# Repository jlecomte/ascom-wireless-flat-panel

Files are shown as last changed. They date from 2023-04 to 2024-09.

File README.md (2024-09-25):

# ASCOM-Compatible Wireless Flat Panel

I do not charge anything to create and maintain these open-source projects. But if you would like to say "thanks" for this project, feel free to send any amount through Paypal using the button below. I appreciate your support!

(https://www.paypal.com/donate/?hosted_button_id=49UXY8F6VVYFA)

* [Introduction](#introduction)
* [Finished Product](#finished-product)
* [User Manual](#user-manual)
* [Pre-Requisites](#pre-requisites)
* [Hardware](#hardware)
* [Bill Of Material](#bill-of-material)
* [ASCOM Driver](#ascom-driver)
  + [Downloading And Installing The Driver](#downloading-and-installing-the-driver)
  + [Compiling The Driver (For Developers Only)](#compiling-the-driver-for-developers-only)
* [Arduino Firmware](#arduino-firmware)
  + [Microcontroller Compatibility](#microcontroller-compatibility)
  + [Compiling And Uploading The Firmware](#compiling-and-uploading-the-firmware)
* [Electronic Circuit](#electronic-circuit)
  + [Schematics](#schematics)
  + [Breadboard Prototyping](#breadboard-prototyping)
  + [PCB](#pcb)
* [Mechanical Components And Assembly](#mechanical-components-and-assembly)
* [Troubleshooting](#troubleshooting)
  + [Changing the 3D model parameters to fit small telescopes](#changing-the-3d-model-parameters-to-fit-small-telescopes)
* [Frequently Asked Questions (FAQ)](#frequently-asked-questions-faq)

## Introduction

This project is the second iteration of my original DIY [ASCOM-compatible flat panel](https://github.com/jlecomte/ascom-flat-panel). It brings a major usability improvement over the first version: It is completely wireless! (whereas the first version relied on a USB type C and a 12V DC cable...) which makes it even easier to use, especially in the dark! It has several other enhancements compared to the original version, and I invite you to check out this video to find out more:

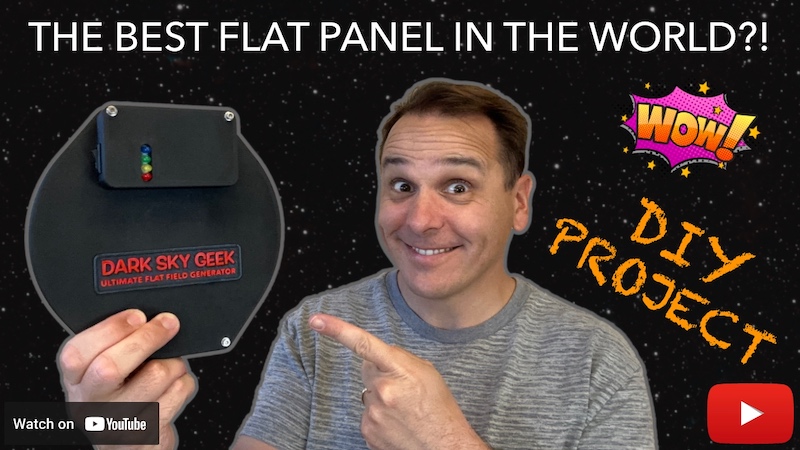
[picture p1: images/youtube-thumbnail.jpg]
YouTube video talking about this flat panel (https://www.youtube.com/watch?v=POvcBwyBBEU)


## Finished Product

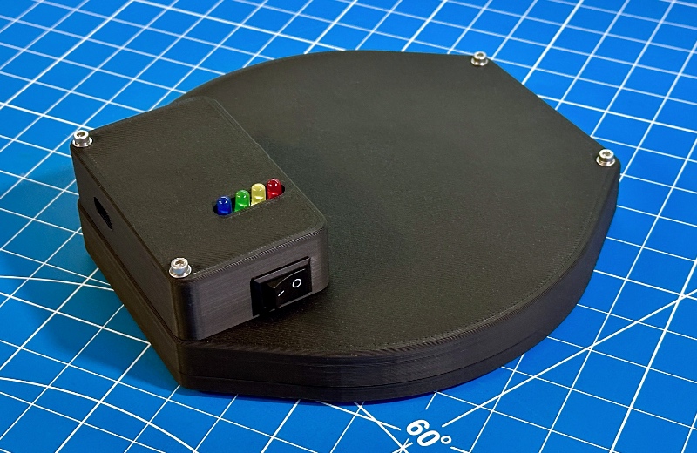
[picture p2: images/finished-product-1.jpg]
Finished product: top of the wireless flat panel


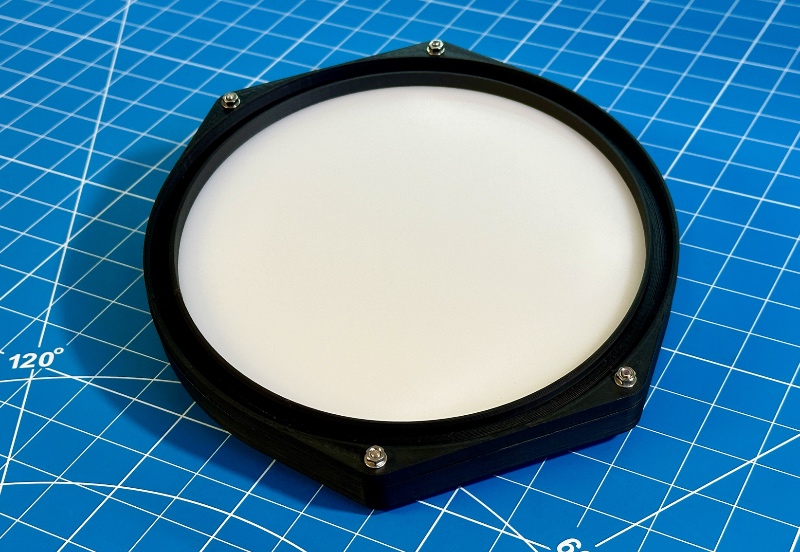
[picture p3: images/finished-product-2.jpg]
Finished product: bottom of the wireless flat panel


## User Manual

Upon turning on the device, the indicator LEDs will show the battery voltage status. After 5 seconds, only the red LED will remain in use, indicating whether a device is currently connected: it will be solid on if a device is connected, or it will continuously blink otherwise.

Before you can connect to the wireless flat panel for the first time, you must select the appropriate device and open the device settings dialog. Here is what that looks like in N.I.N.A.:

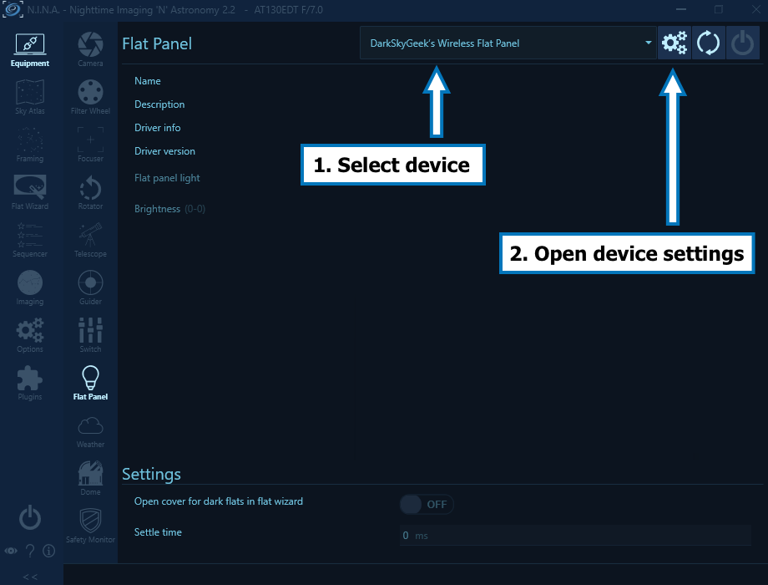
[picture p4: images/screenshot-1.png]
Device selection and opening the device settings dialog


In the device settings dialog, you must then select the appropriate Bluetooth device. The driver will remember your selection, so this is a one-time operation. This step is necessary to ensure that, in the field, where there may be several such wireless flat panels nearby, you are connecting and controlling the right device. Here is what the driver settings dialog looks like the first time you open it. It listens for Bluetooth advertisement packets coming from wireless flat panel devices only.

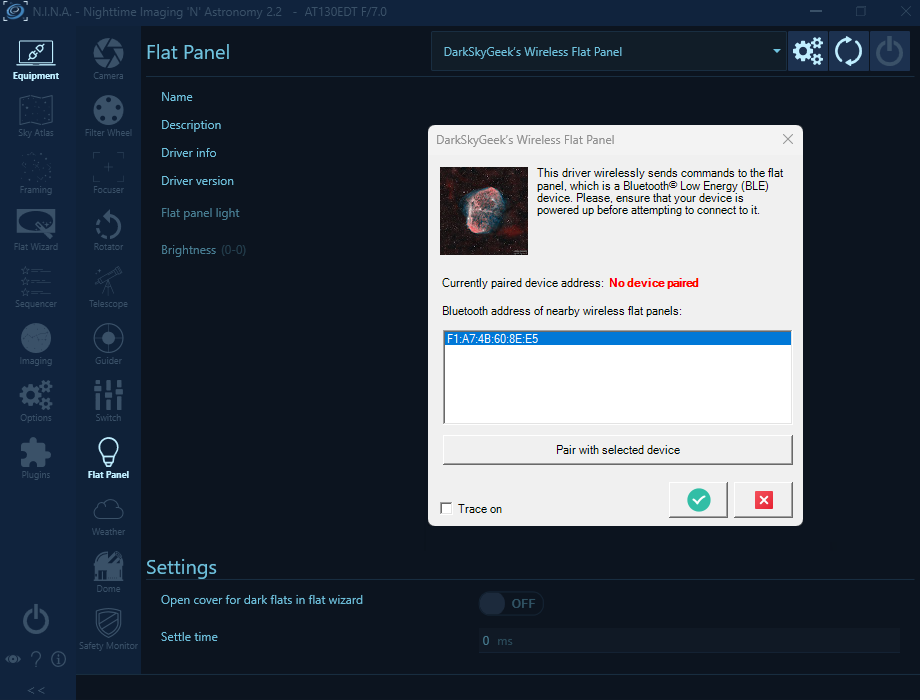
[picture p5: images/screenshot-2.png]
Device settings dialog with no device selected


Of course, the Bluetooth address will be meaningless to you, but that is not important. Click on a Bluetooth address, and click on the "Pair with selected device" button:

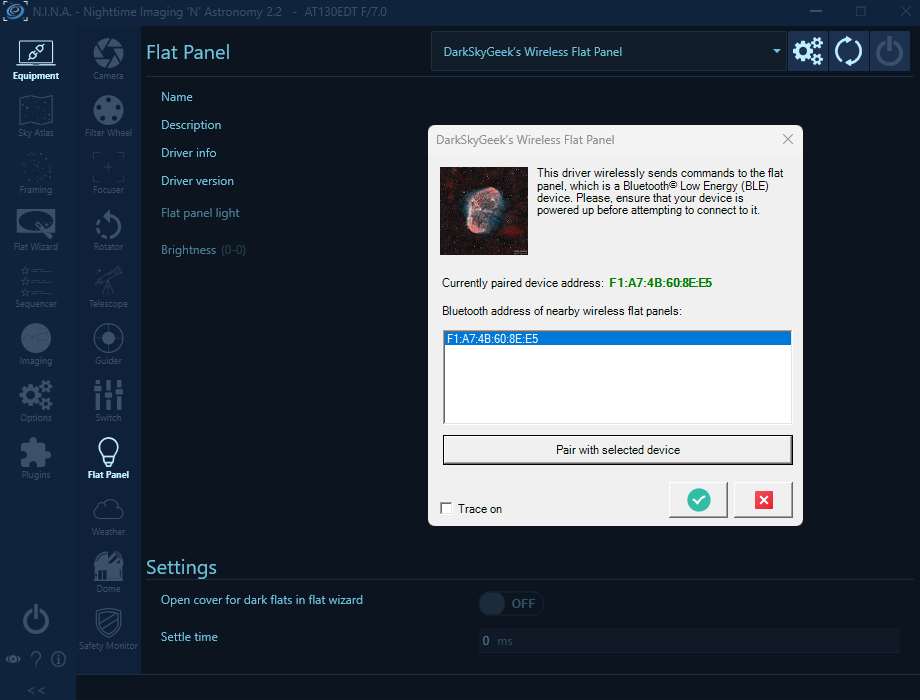
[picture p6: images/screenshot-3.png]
Device settings dialog with device selected


**Note:** This is not really Bluetooth pairing. It is merely device selection. But most users are familiar with the "Bluetooth pairing" terminology, so I used it, even if it is not perfectly accurate from a technical point of view.

Don't forget to validate your choice by clicking on the green checkmark button at the bottom of the device settings dialog! (otherwise, your selection will not be taken into account)

If you do this at home with only one wireless flat panel turned on, you should see only one Bluetooth address in the list, so that's easy. However, if you do this in the field, and there is another wireless flat panel nearby, you may see several Bluetooth addresses. Choose one, connect to it, and turn it on/off to identify which device you are connected to. If you happen to select the wrong device, disconnect from it, open the driver settings dialog again, and choose another Bluetooth address (you will have remembered the Bluetooth address you connected to on the first try...) Simple! Of course, it's easier to do this at home when there is only one device showing in the list... Once the right device has been selected, you can finally connect to it:

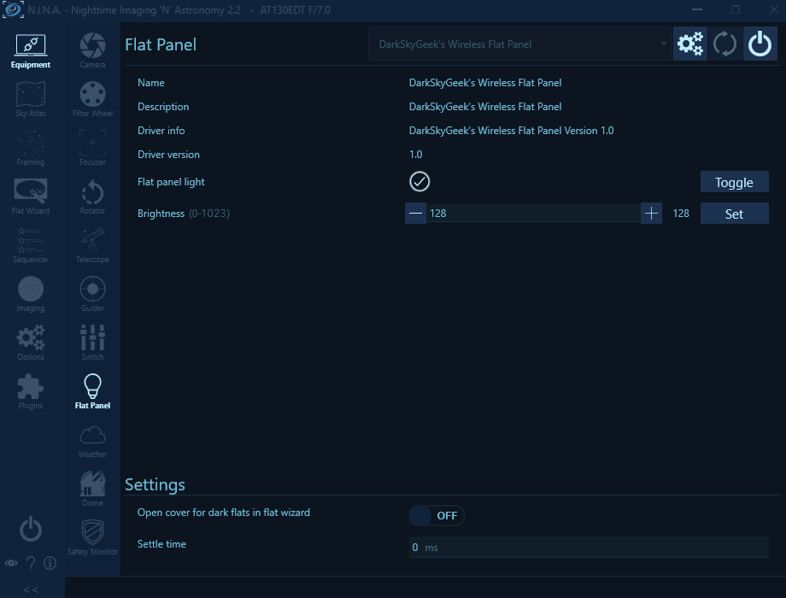
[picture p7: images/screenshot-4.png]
Wireless flat panel connected


## Pre-Requisites

* A Windows computer (Windows 10 or newer)
* [Microsoft Visual Studio](https://visualstudio.microsoft.com/)
* [ASCOM Platform](https://ascom-standards.org/)
* [ASCOM Platform Developer Components](https://ascom-standards.org/COMDeveloper/Index.htm)
* [Arduino IDE](https://www.arduino.cc/en/software)
* [FreeCAD](https://www.freecadweb.org/), a free and open-source 3D parametric modeler. Make sure that you have the latest version installed!
* A 3D printer and a slicer (I use a Creality Ender 3 S1 Plus, and Ultimaker Cura)
* A few basic tools that any tinkerer must own, such as a breadboard, a soldering iron, etc.

## Hardware

* [Adafruit Feather nRF52840 Express](https://www.adafruit.com/product/4062)
* [Natural white 5V LED strip](https://www.amazon.com/dp/B08H51D8QV?tag=darkskygeek-20)
* [FQP30N06L](https://www.amazon.com/dp/B07WHSD3GJ?tag=darkskygeek-20) (logic-level MOSFET)
* An assortment of 1/4W resistors ([example](https://www.amazon.com/dp/B08FD1XVL6?tag=darkskygeek-20))
* An assortment of colored 5mm LEDs ([example](https://www.amazon.com/dp/B09XDMJ6KY?tag=darkskygeek-20))
* A small LiPo battery with a JST-PH 2mm connector ([example](https://www.amazon.com/gp/product/B07BTV3W87?tag=darkskygeek-20)) — The polarity of the connector may be incorrect, so be careful or you may fry the expensive Adafruit Feather board! See note below...
* [Taloya LED Flush Mount Ceiling Light](https://www.amazon.com/dp/B08GX81JB1?tag=darkskygeek-20) — We will take it apart to extract its background disk, Light Guiding Plate (LGP), and diffuser. If you are outside the US and cannot find this item, look for an LED ceiling light on AliExpress ([Here](https://www.aliexpress.us/item/3256804883844716.html) is one that *may* work, I have not verified it) If you go with a different option than the one I selected, you will likely have to make changes to the project, for which I will not be able to support you.
* [3mm thick white acrylic sheet](https://www.amazon.com/dp/B0D2GTXJR1?tag=darkskygeek-20) — We will use that to make the internal diffuser.
* [Rocker switch ON/OFF](https://www.amazon.com/dp/B07XD8J2PL?tag=darkskygeek-20)
* [Brass inserts for 3D printed parts](https://www.amazon.com/dp/B0BXD1YMNS?tag=darkskygeek-20)
* [Assortment of small metric screws, nuts, and washers](https://www.amazon.com/dp/B08JCKH31Q?tag=darkskygeek-20)
* 50mm-long M3 bolts, which you can buy from your local home center or from [McMaster-Carr](https://www.mcmaster.com/products/screws/system-of-measurement~metric/thread-size~m3/fastener-head-type~socket/material~stainless-steel-2/length~50-mm/)
* [Assortment of JST-XH connectors](https://www.amazon.com/dp/B01MCZE2HM?tag=darkskygeek-20)
* [Assortment of electrolytic capacitors](https://www.amazon.com/dp/B07PBQXQNQ?tag=darkskygeek-20)

The following items are technically optional, but highly recommended:

* [Bench Power Supply](https://www.amazon.com/dp/B07GCJ5QHF?tag=darkskygeek-20)
* [Solderless Breadboard](https://www.amazon.com/gp/product/B07LG9V8WQ?tag=darkskygeek-20)
* [Solderless LED strip connectors](https://www.amazon.com/dp/B0BLCQXSXH?tag=darkskygeek-20) — Useful for testing, but cannot be used in the finished product without making changes to the 3D model.

**Important note about the LED strip:** Pick a "natural white" LED strip. Stay away from "warm white" because you will run into some problems with your OIII filter (it does not emit enough in the blue part of the spectrum) or "cool white" because you will have similar issues, but with the H⍺ or SII filters (it does not emit enough in the red part of the spectrum). Also, stay away from so-called "high density" LED strips, they are simply too bright for our application. And finally, note that most LED strips require 12V DC, but in this project, we need one that can be powered with 5V DC. Actually, we are going to power the LED strip using 3.3V DC so that it is not too bright for our application.

**Important note about the LiPo battery:** Do _not_ connect the LiPo battery directly to the microcontroller board via the JST connector, unless you are certain about the battery's connector polarity. See the warning documented on [this Adafruit documentation page](https://learn.adafruit.com/introducing-the-adafruit-nrf52840-feather/power-management-2).

## Bill Of Material

Assuming that you already own a 3D printer, some basic equipment (e.g., a soldering iron), and some basic hardware and electronic components (an assortment of resistors and colored LEDs can be purchased in bulk and reused for a variety of projects — same for metric nuts and bolts or threaded inserts), here is the bill of materials (BOM) for this project (all prices are in USD and accurate as of January 2024):

* Adafruit Feather nRF52840 Express: **$25**
* LED strip: **$11**
* MOSFET: $10 for a pack of 10, so we will only count **$1** for this item in the BOM cost.
* LiPo battery: **$12**
* Taloya ceiling light: **$14**
* Switch: $9 for a pack of 10, so we will only count **$1** for this item in the BOM cost.
* White acrylic sheet: $24 for 3 12"x12" sheets, so we will only count **$8** for this item in the BOM cost.
* PCB manufacturing + shipping: $15 for 5 PCBs, so we will only count **$3** for this item in the BOM cost.
* Miscellaneous: JST connectors, capacitor, resistors, etc. These are so cheap that they do not contribute much to the BOM cost.

**Total cost ~ $75**

While this isn't exactly "cheap", it is significantly more affordable than a commercial unit. For example, PrimaLuceLab sells an excellent, albeit wired flat field generator named Giotto which, for a 6" refractor, costs **$315**. [Deep Sky Dad](https://deepskydad.com/) sells excellent _motorized_ flat panels, but they cost **$300** and up. This should help you decide whether this project is worth the effort.

## ASCOM Driver

### Downloading And Installing The Driver

You can install the ASCOM driver by simply running the executable setup file that you will find in the [releases page](https://github.com/jlecomte/ascom-wireless-flat-panel/releases). By default, it places files under `C:\Program Files (x86)\Dark Sky Geek\Wireless Flat Panel ASCOM Driver`.

### Compiling The Driver (For Developers Only)

Open Microsoft Visual Studio as an administrator (right click on the Microsoft Visual Studio shortcut, and select "Run as administrator"). This is required because when building the code, by default, Microsoft Visual Studio will register the compiled COM components, and this operation requires special privileges (Note: This is something you can disable in the project settings...) Then, open the solution (`ASCOM_Driver\WirelessFlatPanel.sln`), change the solution configuration to `Release` (in the toolbar), open the `Build` menu, and click on `Build Solution`. As long as you have properly installed all the required dependencies, the build should succeed and the ASCOM driver will be registered on your system. The binary file generated will be `ASCOM_Driver\bin\Release\ASCOM.DarkSkyGeek.WirelessFlatPanel.dll`. You may also download this file from the [Releases page](https://github.com/jlecomte/ascom-wireless-flat-panel/releases).

## Arduino Firmware

### Microcontroller Compatibility

The firmware was written specifically for, and tested with, an Adafruit Feather nRF52840 Express. It will likely not work on all Arduino-compatible boards. Please, do not file an issue if you encounter a problem with a different type of microcontroller board.

### Compiling And Uploading The Firmware

* Please, follow the [Arduino IDE setup steps](https://learn.adafruit.com/introducing-the-adafruit-nrf52840-feather/arduino-bsp-setup) published by Adafruit.
* Then, connect your Adafruit Feather nRF52840 Express board to your computer using a micro USB cable, open the sketch file located at `Arduino_Firmware\Arduino_Firmware.ino`, and click on the `Upload` button in the toolbar.

## Electronic Circuit

I included a [KiCad](https://www.kicad.org/) project in the `KiCad_Project/` directory.

### Schematics

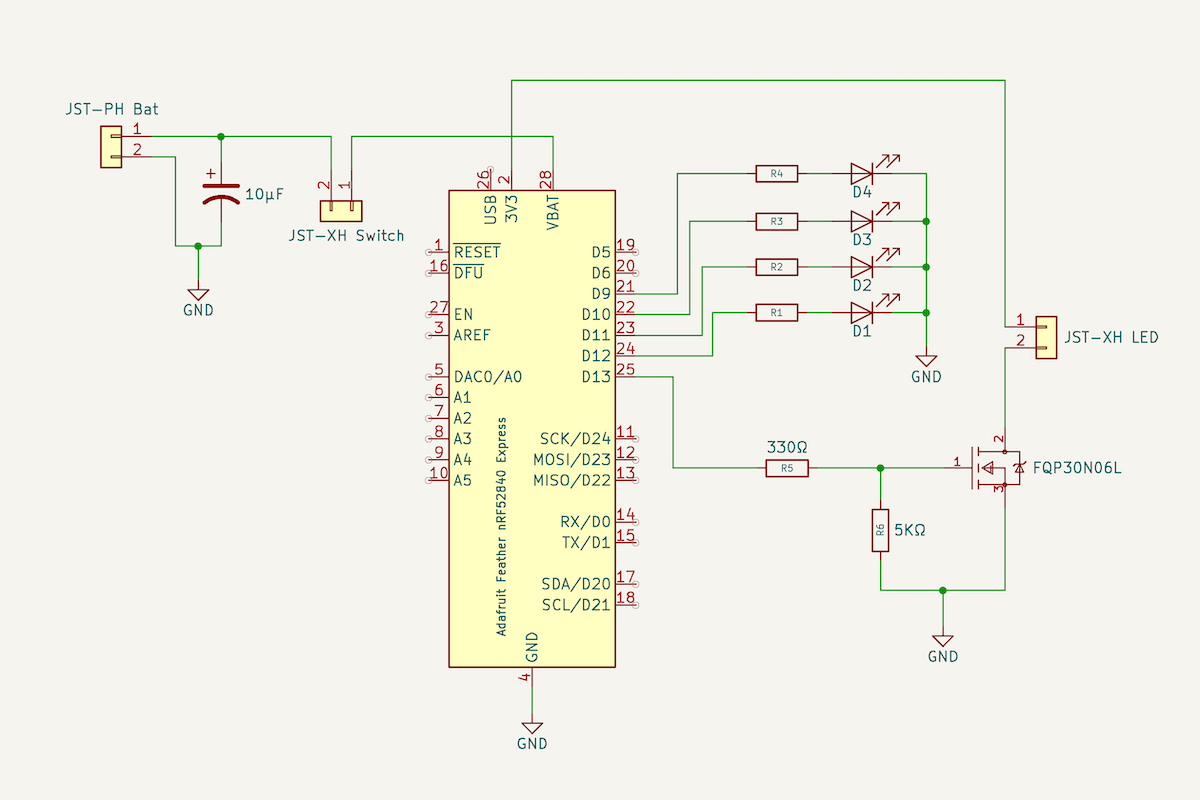
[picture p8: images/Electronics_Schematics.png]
Electronic Circuit Schematics


The values of the resistors R1-R4 depend on the specific colored LEDs you are using. In my case, in order to have all the colored LEDs emit roughly the same brightness, I settled on the following values. You will have to experiment a bit to find out which values work best for you.

* `R1`: 2kΩ
* `R2`: 5kΩ
* `R3`: 1kΩ
* `R4`: 2kΩ

### Breadboard Prototyping

It is critical to prototype this circuit on a breadboard before ordering a PCB, or soldering the components on a perforated board. Here is what my prototype looked like:

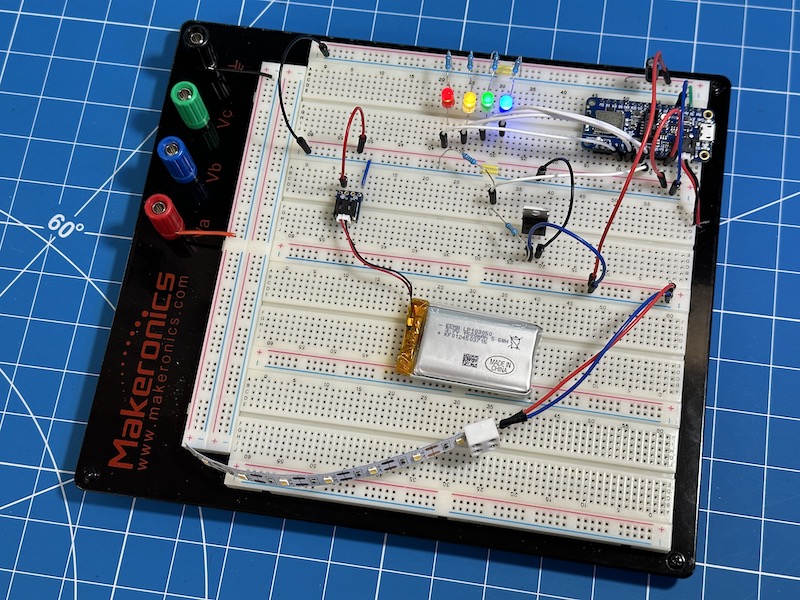
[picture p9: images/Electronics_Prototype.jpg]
Electronic Circuit Prototype


### PCB

Here are 3D renderings of the PCB:

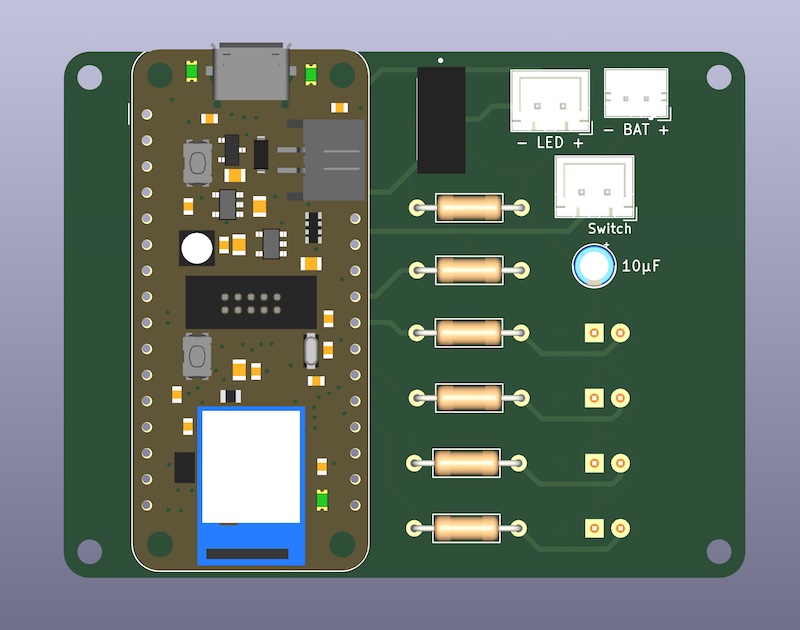
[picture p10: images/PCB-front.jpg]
Electronic Circuit Rendering Front


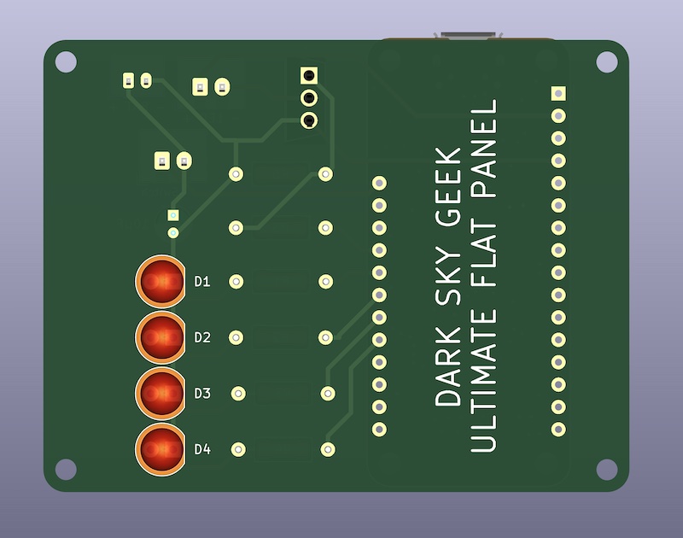
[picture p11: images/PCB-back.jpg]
Electronic Circuit Rendering Back


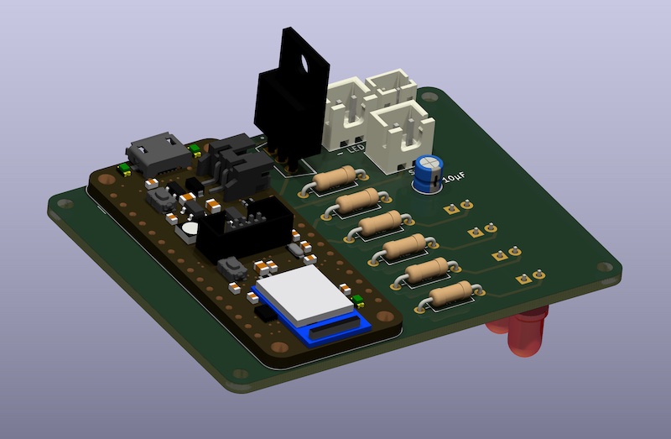
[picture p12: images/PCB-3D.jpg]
Electronic Circuit Rendering 3D


And here is a rendering of the various PCB layers:

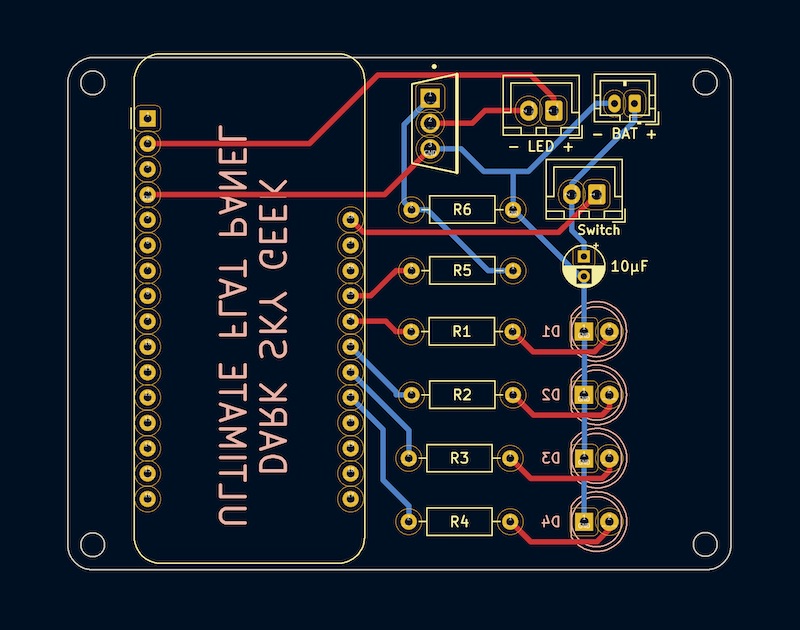
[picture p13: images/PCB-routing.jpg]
Copper traces layout


I exported the Gerber files so that you can have the board manufactured by PCBWay (download the Gerber files for PCBWay [here](KiCad_Project/PCBWay.zip)). When you create your order with PCBWay, keep all the defaults, and set the board size to 66.5mm x 51.3mm. To keep the cost down, select the cheapest shipping method (to ship to the US, I select USPS) and consider doing a "group buy" with other people.

If you want to work with another PCB manufacturer, you will need to open the KiCad project and export the PCB layout to Gerber files. Please, follow the instructions of your PCB manufacturer. They all have slightly different requirements...

Here is a photograph of the control box, which hosts the PCB, after soldering all the components. Note how the switch has been wired.

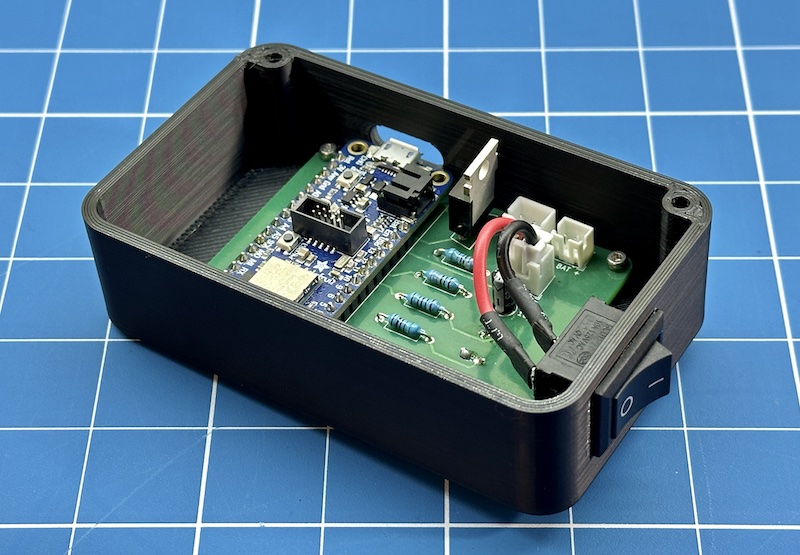
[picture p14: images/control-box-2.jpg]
Control box hosting the completed board with components soldered


The battery indicator LEDs protrude slightly on the other side of the control box:

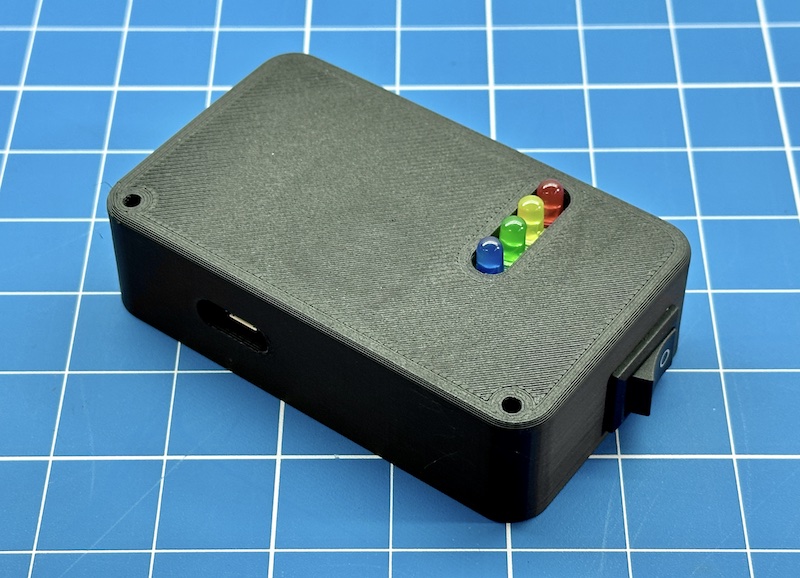
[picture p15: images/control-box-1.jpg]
Control box showing the protruding battery indicator LEDs


## Mechanical Components And Assembly

If you are new to 3D modeling and 3D printing, take a look at [this video](https://www.youtube.com/watch?v=02CWCsGPJ-s) for a quick introduction.

You will need to print a number of parts. Use the 3D model I included in this repository ([`3D_Files/FreeCAD_Model.FCStd`](3D_Files/FreeCAD_Model.FCStd)) to generate STL files for your telescope. Simply open the 3D model in the most recent version of FreeCAD, click on the `Parameters` spreadsheet, and modify the OTA diameter and thickness values. The parametric model will automatically adapt to those values, and you will be able to export your own STL files, which you can then import into your slicer of choice.

In order to achieve good uniformity, this panel has two diffusers. The 3mm thick internal diffuser is made from a white acrylic sheet, and is located right underneath the spacer / right above the LGP. The external diffuser was extracted from the Tayola ceiling light.

To cut the LGP and the two diffusers cleanly and properly, I strongly recommend using a router table. The FreeCAD model contains 3 router templates, which you will need to print. Simply rough cut the component using a scroll saw (for example) and clean it up at the router table, using the appropriate template and a flush cut bit:

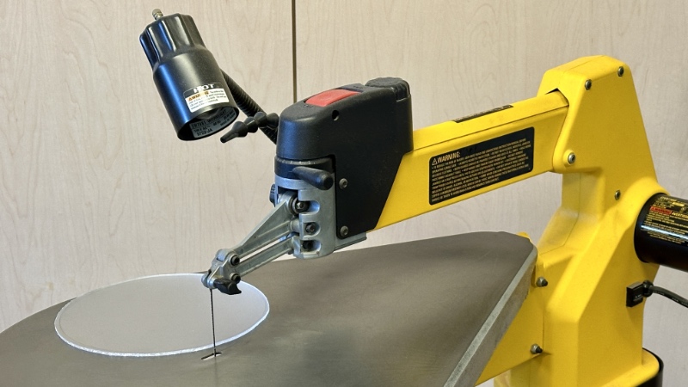
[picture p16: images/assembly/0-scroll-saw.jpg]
Scroll Saw


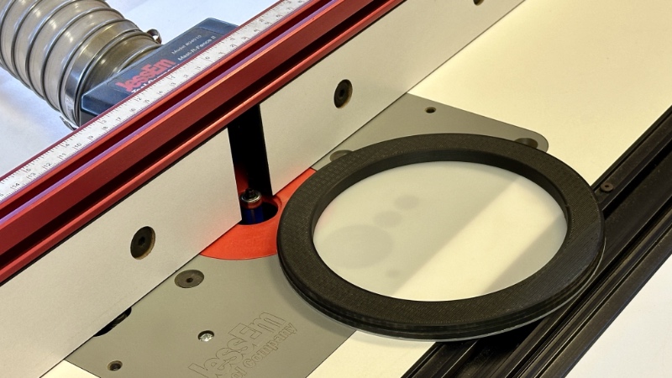
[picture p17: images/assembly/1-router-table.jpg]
Router table


Please refer to this diagram to help you understand where the various components should be placed:

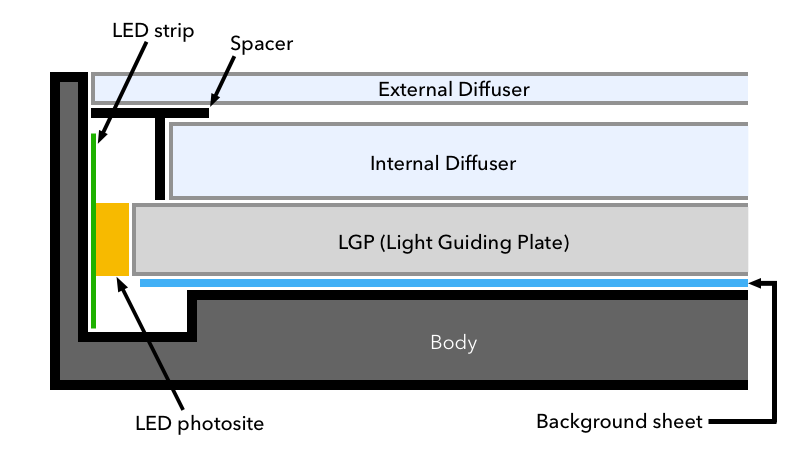
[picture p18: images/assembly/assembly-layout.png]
Assembly layout


Solder flexible wires to the LED strip, and hot glue the connection (I used 5 minute epoxy) to ensure that they never work themselves loose... Then, install the LED strip into the body of the flat panel:

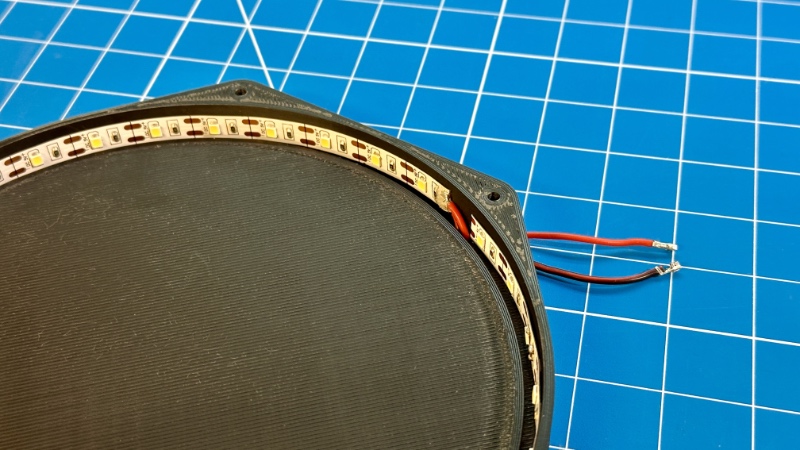
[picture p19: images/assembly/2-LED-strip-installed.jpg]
LED strip installed


Install the background sheet and the LGP. It should be difficult to fit the LGP! The diodes on the LED strip must contact the side of the LGP, so it is normal and expected that it is a tight fit. I had to use a tiny screwdriver to ever so slightly pry the LED strip so I could push the LGP down all the way. Take your time, this is one of the most difficult operations!

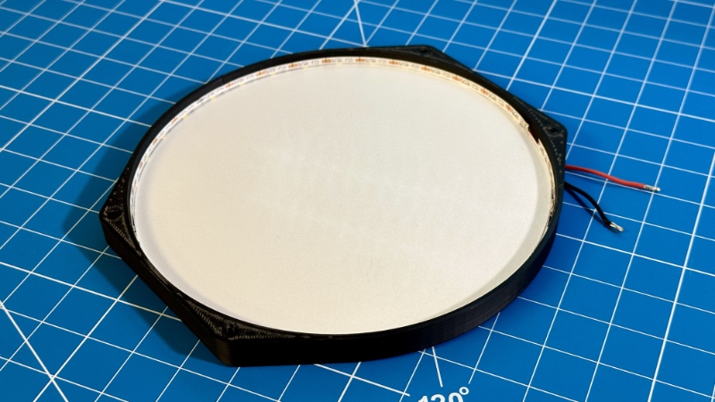
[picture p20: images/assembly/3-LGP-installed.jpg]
LGP installed


Prepare the **internal diffuser**, which is made of a 3mm thick white acrylic sheet, and the spacer, and place them on top of the LGP:

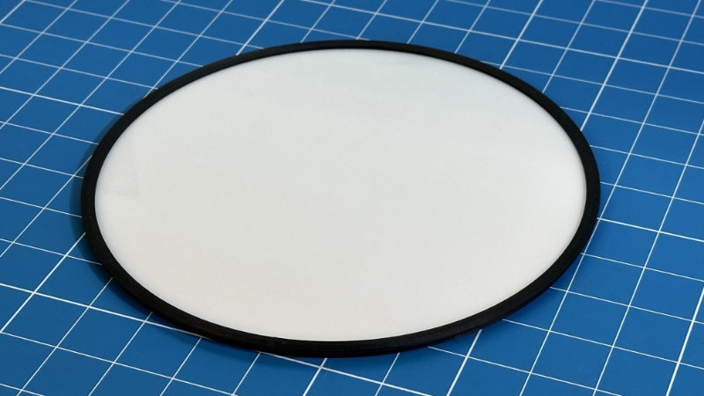
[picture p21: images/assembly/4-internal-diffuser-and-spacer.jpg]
Internal diffuser and spacer


Prepare the **external diffuser**, which you extracted from the Tayola ceiling light, and place it on top of the spacer:

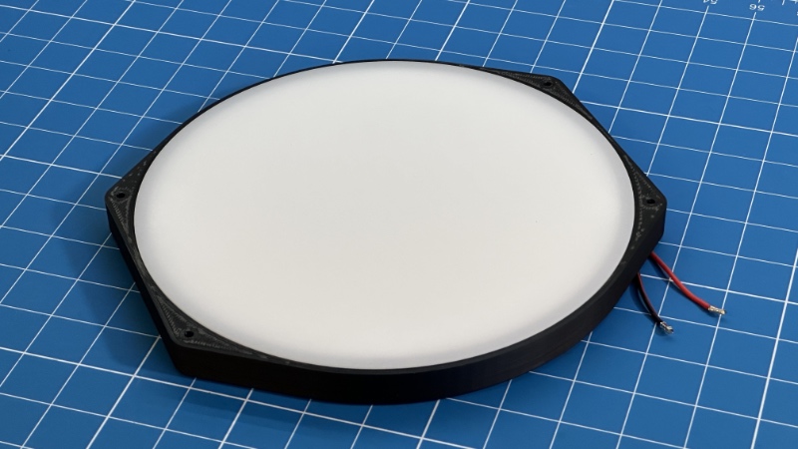
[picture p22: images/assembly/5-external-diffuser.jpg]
External diffuser


Place the front on top of the external diffuser:

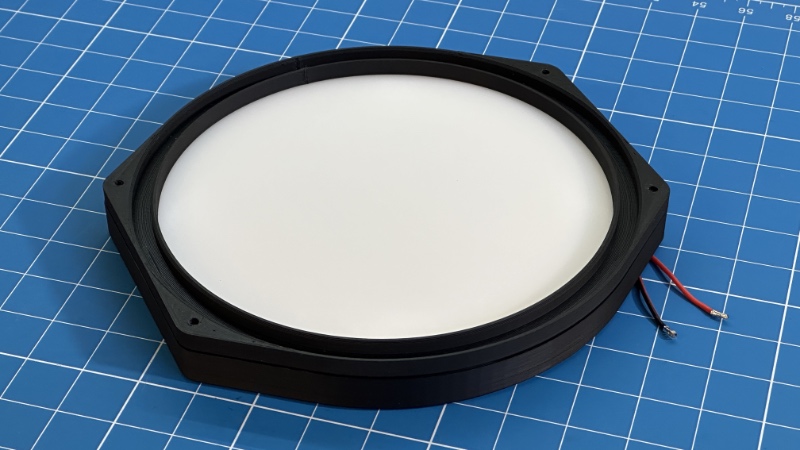
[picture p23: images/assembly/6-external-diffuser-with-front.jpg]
External diffuser with front installed


Install a JST connector for the LED leads, and connect the LED strip inside the control box:

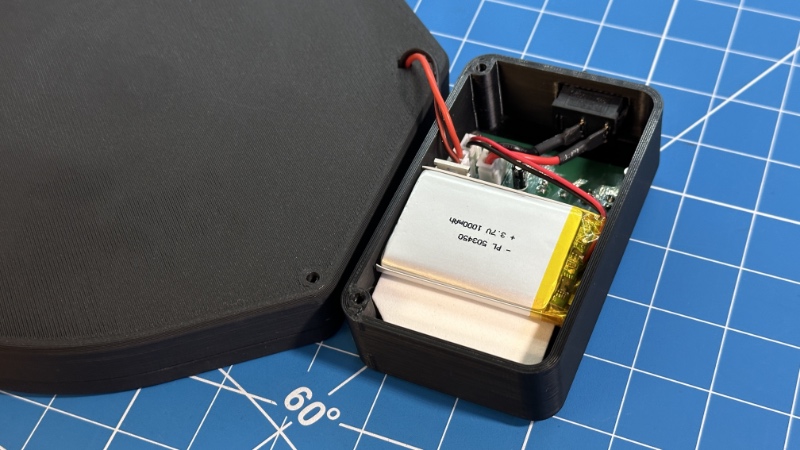
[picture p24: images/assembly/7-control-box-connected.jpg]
Image showing how the LED strip is connected inside the control box


**Note:** I used some foam padding to ensure that the battery was not going to move around.

All you have left to do is to fasten the flat panel using M3 bolts, washers, and nuts.

## Troubleshooting

### Changing the 3D model parameters to fit small telescopes

If you open the 3D model in FreeCAD and update the `OTA Outside Diameter` parameter to fit a much smaller telescope than this panel was originally designed for, you may get a `Recompute failed` error. This is because the minimum size of the panel is dictated by the length of the PCB. To fix this, set the `OTA Outside Diameter` parameter to a value larger than what you actually need, e.g., `130mm`, and increase the `OTA Thickness` parameter to a much larger value, e.g., `50mm` (in FreeCAD, you can make measurements using the `Draft` workbench to ensure that you have the proper value before printing any of the parts). The panel will be larger than what you actually need, but it will work. Play with the parameters and find what works for you.

## Frequently Asked Questions (FAQ)

**Question:** Can you make this for me? I'll pay for it!

**Answer:** I really wish I could. Unfortunately, I do not have the time necessary to manufacture this product for a large number of people.

**Question:** OK, I decided to build it, but I am stuck. Can you help me?

**Answer:** I will do my best, but I cannot provide any guarantee. Please, [file an issue](https://github.com/jlecomte/ascom-wireless-flat-panel/issues).

**Question:** Can you incorporate your DIY [ASCOM-compatible telescope cover](https://github.com/jlecomte/ascom-telescope-cover) into this project?

**Answer:** I am not interested in consolidating this project with my DIY [ASCOM-compatible telescope cover](https://github.com/jlecomte/ascom-telescope-cover) because, in my case, it would add too much weight to the front of my already front-heavy OTA, making it more difficult to balance, and causing all kinds of issues with the camera possibly hitting the tripod legs since the OTA would have to be moved back to provide proper balance. If you have a fully remote setup, I recommend looking at the excellent motorized flat panels sold by [Deep Sky Dad](https://deepskydad.com/). Otherwise, you can use a large and affordable LED tracing panel, which you can easily find on Amazon. Modify it to be ASCOM-compatible (see [this CloudyNights article](https://www.cloudynights.com/topic/536533-diy-alnitak-flat-panel/)), and position it vertically. Then, simply slew the telescope to it (the telescope will be in a horizontal position). Most modern Go-To mounts support storing several custom positions, so that makes it even easier! Anyway, you have a few options...

**Question:** Is this panel uniform enough?

**Answer:** Absolutely! Please refer to [my evaluation of the uniformity of this panel](https://github.com/jlecomte/circular-led-flat-panel-evaluation) for more information.

**Question:** Is this compatible with ZWO's ASIAir?

**Answer:** Unfortunately, no. As far as I know, ASIAir does not support ASCOM-compatible flat panels of any kind. That is because ASIAir is a closed ecosystem, and it is not possible to install additional drivers on an ASIAir unit. Additionally, ASIAir is based on the INDI platform, and I have not released an INDI driver for this device.

**Question:** My antivirus identifies your setup executable file as a malware (some kind of Trojan)

**Answer:** This is a false detection, extremely common with installers created with [Inno Setup](https://jrsoftware.org/isinfo.php) because virus and malware authors also use Inno Setup to distribute their malicious payload... Anyway, there isn't much I can do about this, short of signing the executable. Unfortunately, that would require a code signing certificate, which costs money. So, even though the executable I uploaded to GitHub is perfectly safe, use at your own risk!

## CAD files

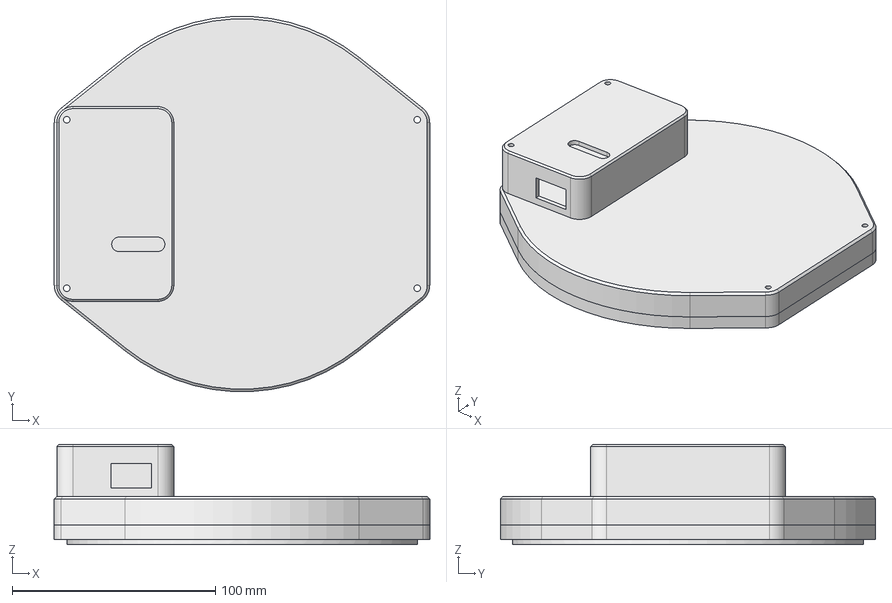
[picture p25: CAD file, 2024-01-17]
3D_Files/FreeCAD_Model.FCStd
184.6 x 184.4 x 49.2 mm
Front
Spacer
Circuit_Board_Box
Cover

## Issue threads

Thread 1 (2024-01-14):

PCBWay information

alexd106, 2024-01-14:
Hi, First, thanks for putting this excellent project together. I would like to suggest an enhancement to the documentation regarding information required for PCB manufacturer for those of us who have never used this service before. Before uploading the gerber files to PCBWay, the user will need to specify a number of options like PCB dimensions, material, min hole spacing etc. Possibly these are all default values (except dimensions which I can get from Kicad) but it would be great if you can add some information regrading this to the documenttation. Many thanks.

Wellco, 2024-01-14:
@alexd106 I just uploaded Julien's zip file into the PCBway viewer and then took a few mins to review the design based on resources here in GITHub. Then I clicked order and it looked fine to me, or am I missing something. I have never used PCBway before so I'm not an expert.

alexd106, 2024-01-14:
@Wellco thanks for your response, I haven't used it before either and am probably overcomplicating things! I didn't use the PCBWay viewer (didn't know it existed!) just went to the PCBWay website and started to go through their process (you need to specify basic options before you can upload the zip file this way). Your way seems much more sensible :). I noticed that when you click on the 'get instant quote' in PCBWay viewer none of these options are prefilled in the quote but perhaps that doesn't matter if they have the PCB  file.

Wellco, 2024-01-14:
@alexd106 I don't know if this helps, but go to PCBway (https://www.pcbway.com/project/OnlineGerberViewer.html), then load Julien's zip file. Then have a look or just click "get and instant quote". I think that's all there is to it. Let me know if you think I am wrong.

jlecomte, 2024-01-14:
Addressed in [this commit](https://github.com/jlecomte/ascom-wireless-flat-panel/commit/bf930bba483c1226f2a90652a6875b9ac90d640e). Thanks!

alexd106, 2024-01-14:
Hi, noticed your closed issue regarding the non-availability of the Tayola
diffuser in the UK. I'm also in the UK and found this on amazon
https://www.amazon.co.uk/gp/product/B09YRFC3JS/ref=ox_sc_act_title_2?smid=A1NNPUA7EKFNWH&th=1
Haven't tried it yet but have ordered and will see if it fits (or the
freecad model can be modified).
HTH

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

Closed 2024-01-14.

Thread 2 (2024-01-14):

I'm not able purchase the Taloya ceiling light.

Wellco, 2024-01-14:
I'm in the UK and can't get the Taloya ceiling light; Is it possible to document some basic specs for a generic LED strip?  for instance would this be an option

https://www.aliexpress.com/item/1005004714205956.html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

Many thanks

jlecomte, 2024-01-14:
The Taloya ceiling light is used for the LGP, the background sheet and the external diffuser, so it is pretty important. If you cannot purchase the one I listed, look for other options. Here is an example that is even cheaper, from AliExpress: https://www.aliexpress.us/item/3256804883844716.html (I have not verified that it will work, you may have to make changes to the project, at which point I cannot support you)

That LED strip you linked to is 12V. You need to use a 5V LED strip (that is documented in the README, look for `Important note about the LED strip`)

jlecomte, 2024-01-14:
Addressed in [this commit](https://github.com/jlecomte/ascom-wireless-flat-panel/commit/9dee3179851d9ea506e4c751baa3d76092c932b1). Thanks!

ktwb, 2024-08-12:
Further to this issue, what might be helpful is some sort of link or guidance to how to tell if what you've taken out of other models of these lights is an LGP. I've got a piece of something out of a light of the model you've linked but I'm not actually sure if it's an LGP or something else entirely.

I'm not sure it is because it doesn't have the properties you've described in a light guiding plate but the construction of the light is extremely similar to the design we're using here for the LGP (LEDs flush with a large disc of something) so...

Wellco, 2024-08-12:
In reality the light guiding plate is not as critical as you might think. In my experience using device  with NINA the LEDs are usually near their lowest output, and because the image is wildly out of focus (the device is sitting on the end of your scope) the light is perfectly diffused for your flats.

Closed 2024-01-14.

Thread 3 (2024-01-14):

Taloya alternative?

alexd106, 2024-01-14:
For those based in the UK who are unable to source the Taloya ceiling lamp, [this might be a suitable alternative](https://www.amazon.co.uk/gp/product/B09YRFC3JS/ref=ox_sc_act_title_2?smid=A1NNPUA7EKFNWH&th=1). I haven't tried this yet, but have ordered one and will report back. @jlecomte do you know the thickness of the Taloya diffuser? Thanks

Wellco, 2024-01-14:
@alexd106 Thanks Alex. That is very useful!

jlecomte, 2024-01-14:
The thickness of the external diffuser is a parameter of the 3D model. Look at the spreadsheet in the FreeCAD model.

acocalypso, 2024-03-10:
I build mine using that lamp
https://a.aliexpress.com/_EyoMt5r

As I have no 3d printer I made a poor man's build :)
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

Wellco, 2024-03-10:
@acocalypso How is the LED light diffusion with your setup? Mine is not that, even to the naked eye, but when I compare with flats via other methods they seem to be fine. I think the reason is the light is so far our of focus and so very dim when NINA adjusts the intensity I just about get away with it.

acocalypso, 2024-03-10:
It's also not that even but I'm still missing the external 3mm diffuser, currently I'm using everything from the led lamp itself.
I did some tests 2 days ago and the produced flats where usable with Nina.

alexd106, 2024-03-24:
Sorry it's taken me a while to revisit this @Wellco. I have just finished putting my flat panel together and can confirm that the light I [linked to before](https://www.amazon.co.uk/gp/product/B09YRFC3JS/ref=ox_sc_act_title_2?smid=A1NNPUA7EKFNWH&th=1) works fine.

It took quite a bit of jiggery-pokery to get the LGP to sit against the LEDs as the tolerances are spot on but managed to get there in the end.

Thanks again @jlecomte

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

Wellco, 2024-03-24:
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
Looks very nice Alex. Have you tried it yet? It's very satisfying to use.

nunoagameiro, 2024-06-26:
First, congrats for the project.
For those (like me) who don't understand anything about LGP , except the thikness of the plate, can you tell what are the major diferences that make suitable or not one LGP plate for the project ?

Wellco, 2024-06-26:
> First, congrats for the project. For those (like me) who don't understand anything about LGP , except the thikness of the plate, can you tell what are the major diferences that make suitable or not one LGP plate for the project ?

The LGP is a way to make the light diffuse and therefore even across the entire disk of the device. I had problems with this myself since I'm in the UK and could not buy the same donor  light that Julien used in his video.  However I'm not sure the light has to be that even or diffused, this is because the light is so far out of focus (its on the end of your telescope after all) and when I use mine with NINA the LEDs are near the minimum brightness. I compared my flats with other methods and could not see any differences.

If you haven't already tried, I would give the project a go. For me it was/is immensely rewarding and it makes the task of creating flats ridiculously easy.

nunoagameiro, 2024-07-02:
I've tried with a diferent LGP (i'm not able to find the Taloya brend in Portugal, so i had to use another one.

I'm using it with a 102mm telescope and a QHY268 and i'm having a lot of dificulties to get flats with more than one second, that's why i asked if LGP of Taloya are diferent of the ones used in another brands.

Wellco, 2024-07-02:
> I've tried with a diferent LGP (i'm not able to find the Taloya brend in Portugal, so i had to use another one.
>
> I'm using it with a 102mm telescope and a QHY268 and i'm having a lot of dificulties to get flats with more than one second, that's why i asked if LGP of Taloya are diferent of the ones used in another brands.

Why do you need flats more than one second? I just let NINA control the process and it seems to do a fine job. I can't remember but I think my flats would be around 0.9 of a second.

I don't believe the Taloya LGP is anything special (shoot me down if I a wrong), so any plate from a similar spec LED light fitting should do the job.  Good luck

cayalag, 2024-10-28:
For those of you in Europe looking for Taloya LED panels... after a lot of research I found a shop in Spain that supplies them in different sizes  (https://www.luzenled.com)

I have just received a 40 cm one, so I can trim it to fit a C11.

LeeNHawaii, 2025-04-19:
What type of material did u use to print the 3D parts and what was the nozzle size?

alexd106, 2025-04-19:
> What type of material did u use to print the 3D parts and what was the nozzle size?

Mine was printed in PETG with a 0.4 mm nozzle.

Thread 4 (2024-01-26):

Schematics numbering

iancward54, 2024-01-26:
The schematics numbering for the nRF52840 seems to bare no relationship to the numbering on the actual board I am a little confused what goes where.

jlecomte, 2024-01-26:
I do not use the `nRF52840` chip directly. I use the [Adafruit Feather nRF52840 Express](https://www.adafruit.com/product/4062) board, which uses the `nRF52840` chip internally.

iancward54, 2024-01-26:
I have the Adafruit Feather nRF52840 Express board but the numbering on the board is different than your drawings, you have D5 to D13 which don't exist on the board. It's rather confusing.

Ian

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

jlecomte, 2024-01-26:
Here is the pinout for that board:

https://learn.adafruit.com/introducing-the-adafruit-nrf52840-feather/pinouts

It does have D5 -> D13 pins.

iancward54, 2024-01-29:
Thanks for the help so far.

Everything is connected, Bluetooth is working but no lights on the ring of LED’s.

JST-XH LED number 1 on your drawing to earth is 3 volts, number 2 to earth is 1.16 volts.

I am thinking FQP30N6L maybe wired incorrectly I have attached the wiring diagram for this component, D goes to the LED’s, G goes to the resistors and S to earth. The pins left to right are labelled G-D-S.

So close.

Ian

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

Closed 2024-01-26.

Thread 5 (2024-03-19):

Maximum diameter of the flat panel...

rstjean24, 2024-03-19:
Bonjour Julien, I am planing to build myself the flat panel described here. I own a Celestron 9 1/4'' SCT and I am wondering if it's possible to adapt the panel to such a diameter. I understand there no issue for at least 151 mm (your own telescope) but is the illumination for up to 235 mm feasable ?

acocalypso, 2024-03-19:
> Bonjour Julien, I am planing to build myself the flat panel described here. I own a Celestron 9 1/4'' SCT and I am wondering if it's possible to adapt the panel to such a diameter. I understand there no issue for at least 151 mm (your own telescope) but is the illumination for up to 235 mm feasable ?

Which that diameter I don't think that a led ring can illuminate the whole area. But this is just my personal thought

jlecomte, 2024-03-20:
The only way to find out is to try it. I think it will work.

Closed 2024-03-20.

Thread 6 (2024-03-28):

Minimum OTA outside diameter : <107.6mm not possible

fiesiker75, 2024-03-28:
Hi

I`d really like to adapt this project for a Skywatcher 72ED (72mm outer diameter). However if the OTA diameter (ota_outside_diameter) is set below 107.6mm I get a "Recompute failed!" error for the Pad001 object.

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

19:59:27  Updating geometry: Error build geometry(10): gp_Circ::SetRadius() - radius should be positive number
19:59:27  Invalid solution from LevenbergMarquardt solver.

I realise that this project is intended for larger telescopes. The issue seems to be that the OTA hole is smaller than the body and front peices. Is there a simple way to fix this issue?

Thank you in advance

jlecomte, 2024-03-29:
I think there is a fix possible, but it won't be pretty, i.e. the flat panel will be quite a bit bigger than your OTA, but the lip will fit the OTA. Let me think about it. I won't be able to get to this for a couple of months, but I'll see what I can do. Note: The minimum size is dictated by the size of the PCB.

jlecomte, 2024-03-29:
Added a workaround in [this commit](https://github.com/jlecomte/ascom-wireless-flat-panel/commit/3d156d5a81893f9c65a45382ab6d22e80d2a066a). That's the best I can do. I don't want to sink hours of work into this (free) project :)

Closed 2024-03-29.

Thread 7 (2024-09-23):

tips for the people starting to build this

cageman1970, 2024-09-23:
I struggled quite a lot to build this because i followed the instructions very precisely, and when they were not clear i followed the pictures. When these were unclear i searched online.

- At first it didnt work, even got a burning smell...
- Finally decided to turn a few things around and... everything seems to function!
The reason:

the leds
1) 'normally' the indicator for led diodes is a square marker for the positive, and a round marker for the negative (if found that online, and thats the case for the battery, led and switch connections too). But on the PCB somehow these are reversed for the led diodes and there are no indicators for the + and -. Looking back the routing drawing makes it clear (red is positive) but i'm an electrical noob...
> So: the long pin of the diode has to be inserted in the round marked hole!

The Mosfet thingy
I just followed the pictures, so installed the Mosfet thingy with the metal back facing the Led and BAT connectors. I think that caused a bunring smell when i attached everything. And nothing worked, none of te indicator leds lit up (maybe due to the point above too). When i saw another build on youtube where they had the mosfet reversed (metal back facing the Adafruit) i  decided to give that a go. And voila!
> So the Mosfet orientation seems important too. I have no idea how to identify the right direction.

Perhaps this can be added to the instructions? Like i said i'm an absolute Noob. I just ordered the parts and decided to try it, have no clue what to do with the reamining 9994 resistors (ordered a bag full of all kinds of values). But it all is doable, just go gung-ho and start with it!

The softwarepart is the next thing i have to test, so no comments on that part for now

jlecomte, 2024-09-23:
Thanks for the feedback. Please note that the README contains this very important tip:

> It is critical to prototype this circuit on a breadboard before ordering a PCB, or soldering the components on a perforated board.

It's unclear from your description that you attempted to prototype this project. It might have saved you a bit of time.

Closed 2024-09-23.

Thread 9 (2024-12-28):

Low brightness of the panel even at maximum power.

giangitesta, 2024-12-28:
Hi @jlecomte,
I have made your beautiful project twice and everything works perfectly.
The only problem I have encountered is the low brightness of the panels even at maximum power.
With narrowband filters this implies exposures on the order of 240 seconds to get an acceptable flat. I would like to increase the brightness consistently.
I have already tried:
- varying the pwm frequency divider parameter in the firmware.
- externally powering the mosfet with external 5 vcc by putting the grounds in common but nothing
Do you have any advice for me?
Maybe vary the voltage divider that drives the mosfet?
I am fairly familiar with electronics but I would like to be sure how to proceed.
I thank you and wish you a happy holiday season.
Gianluca

jlecomte, 2024-12-31:
I cannot provide any advice because there could be at least a dozen reasons for this, ranging from bad components to improper wiring. You will have to troubleshoot on your own (consider it a fun challenge :) Best of luck!

jhornos, 2025-02-07:
Hello,

Great project.
I have the same problem i have mount the flat pannel and i have conected with Nina correctly. But the bright is very low.
Did you found a solution?
Thanks

Closed 2024-12-31.

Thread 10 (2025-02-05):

Values for resistor R1 to R4

jhornos, 2025-02-05:
I am building the flat panel.
It is a brilliant project. I am enjoying doing it.

I see in readme file that the values used are:
R1: 2kΩ
R2: 5kΩ
R3: 1kΩ
R4: 2kΩ
These values seem to be very hight. I tried with these values and the bright is very low.
I have use the value of 3.7V. I suppose that 3.V is output votage for D9-D12 pins, isn't it?
The calculation for my LEDs are:
**Colour________ V led________ R  (20mA)________ R (20mA) Commercial Value**
Blue__________ 2,63v________ 53,5 Ohm___________68 Ohm
Green________ 1,93v________ 88,5 Ohm__________100 Ohm
Yellow________ 1,84v________ 93 Ohm___________100 Ohm
Red___________1,68v________ 101 Ohm__________100 Ohm

I have tried with these and the bright is ok.
Is there anything that I am missing?

Thanks

jhornos, 2025-02-07:
Solver i have increased a little bit higher. 150, 180 and 340 ohm

Closed 2025-02-07.

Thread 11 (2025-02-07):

Working but wirh very low brght

jhornos, 2025-02-07:
Hello,

Great project.
I have the same problem that another user had. I have mount the flat panel and i have conected with Nina correctly. But the bright is very low.
Any sugestion?

Thanks

jhornos, 2025-02-08:
I am checking all
I have connected the led panel directly (out of the circuit) to a power source of 3,3V and works ok (good bright).
I have connected the battery directly to the led panel (without the circuit) and ok (good bright).
So, the problem is in the circuit.
I have made a revision of the soldering, and all seems to be ok. The circuit is no complex.
Connecting all to the circuit, when push to switch on in Nina and set the values practically no light is visible, it is needed to switch of all light to see the led brightness.

jhornos, 2025-02-09:
The fist I did is to change the MOSFET to another, I ordered a packet on 10 to analyse if the first one was broken.
The bright continues low, but i sow it better, perhaps because i did the test at night and when you switch of the light there is no background lights.
I have measure the voltage in the led strip with different values in Nina and the results:
- 2023: 2.466V
- 100: 2.223V
- 500: 2.294 V
The voltage between S (3) And D (3) is 0.8V. Is this usual?
I am going to test with the camera so see if it is enough
As i see the MOSFET at low value in Nina increase the voltage between S and D and at hight value is reducing, but with a very low margin, at value of  50 in Nina is 1.09V. Is working as a variable resistor?
It is anyway to low the voltage between S and D between 0.8 V?

Thank in advance

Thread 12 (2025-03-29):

Circuit Board

rbolser, 2025-03-29:
I have a few circuit boards available if anyone is interested. They were made by JLCPCB. Cover my costs and shipping is all I ask.

LeeNHawaii, 2025-04-19:
I am interested in one of your boards.  What is the cost to include shipping to Hawaii..Zip 96822?

rbolser, 2025-04-19:
Looks like USPS is the cheapest at 10.65 for Priority Mail.

rbolser, 2025-04-19:
> I am interested in one of your boards. What is the cost to include shipping to Hawaii..Zip 96822?

looks like USPS is the cheapest at 10.65

LeeNHawaii, 2025-04-20:
Pls send me an email at kojaklazyATgmailDotCom to discuss payment and shipping.  Mahalo

Murz61, 2025-04-27:
I would be interested in one of the boards if you still have one.  mark.mruczek@yahoo.com. Shipping would be to Houston TX.

rbolser, 2025-04-28:
Send me your name and email address and we can figure out the details.

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

Murz61, 2025-04-28:
Hi,

Thank you for the quick reply.
Name: Mark Mruczek
Email: ***@***.***
________________________________
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

Murz61, 2025-04-28:
This may be blocking my email so here it is.

mark_dot_mruczek_at_yahoo_dot_com

Name: Mark Mruczek

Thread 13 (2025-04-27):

Combine ASCOM Compatible Cover V2 with the wireless Flat Panel

Murz61, 2025-04-27:
Has anyone actually combined this flat panel with the ASCOM Compatible Cover V2? My question or where I think I will be stuck is with the board. I am assuming I Can use the board design of the wireless flat panel but will need to add a connection for the servo motor for the cover but not sure how to do this. I was hoping someone and actually combined the two.

Thank you,

Mark M

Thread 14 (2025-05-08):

Lithium Battery vs frozen temperature

pat685, 2025-05-08:
I look your concept and I would like to try to build it.

I live in Canada. My telescope is in observatory all the time. In winter, the temperature below under -20C (or -4F). But I use my telescope at -20C or above. Will the 3.7V 1000mAh 503450 Lipo Battery Rechargeable Lithium Polymer Ion Battery Pack with ph2.0 Connector still work à this temperature ?

I think lithium batteries lose a lot of efficiency at these temperatures.
Thanks

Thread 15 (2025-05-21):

Version 1 ASCOM With Seedruino Driver Connection Issue

astromiester1, 2025-05-21:
I didn't see a place for the first version anywhere to get this message to you, so I am trying here...

I have loaded the firmware and ASCOM driver for version 1 non wireless using Seeduino and can't talk to board using ASCOM driver in NINA.

I noticed the Seeduino after loading firmware disconnects from com port leaving bootloader mode which gives no avenue to connect wo a com port visible.  If you double reset the Seeduino to get com port back the ASCOM driver still doesn't connect.. Any ideas?

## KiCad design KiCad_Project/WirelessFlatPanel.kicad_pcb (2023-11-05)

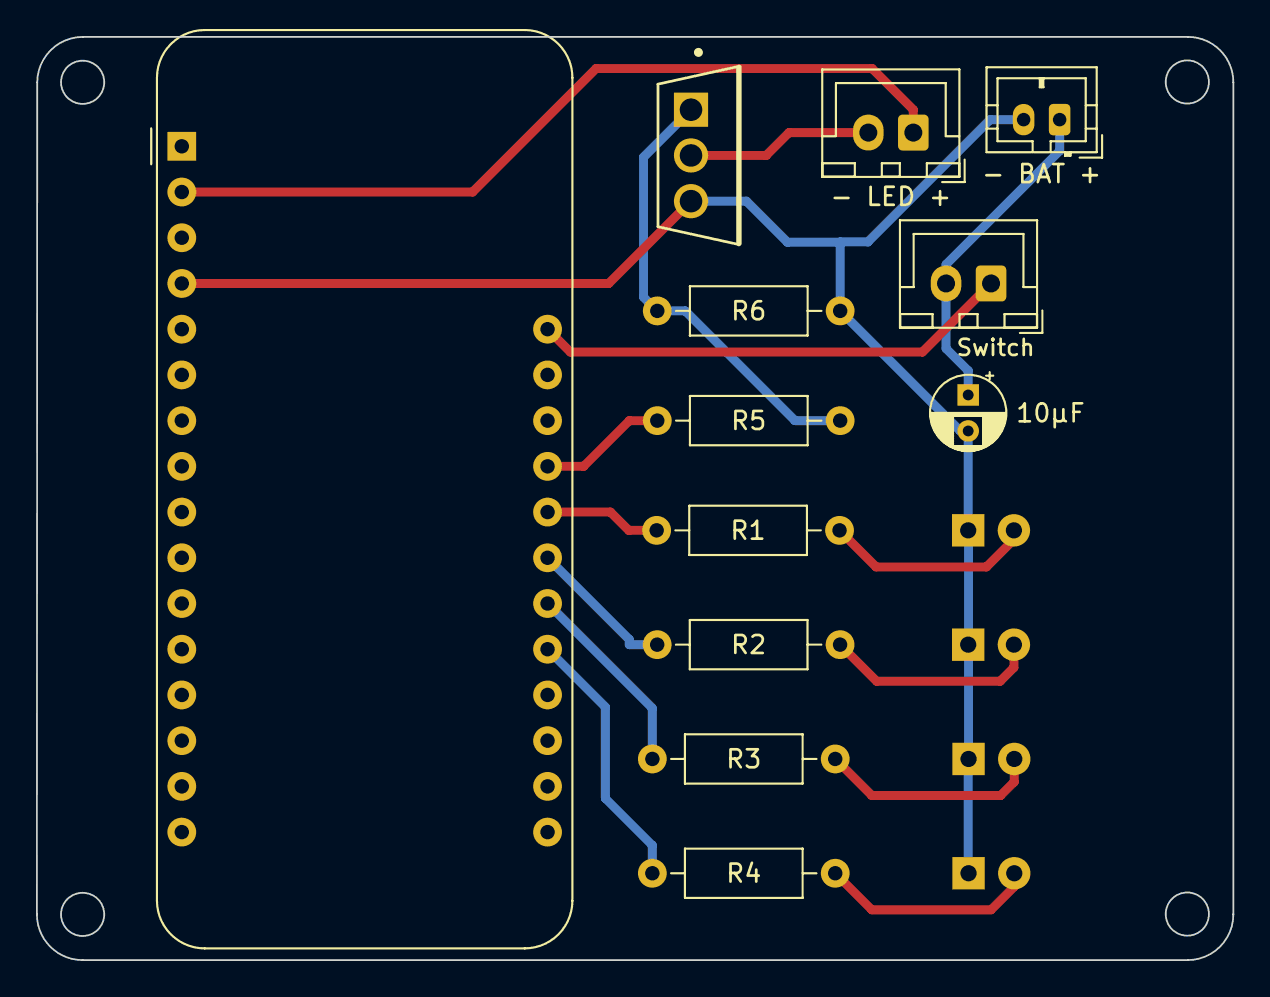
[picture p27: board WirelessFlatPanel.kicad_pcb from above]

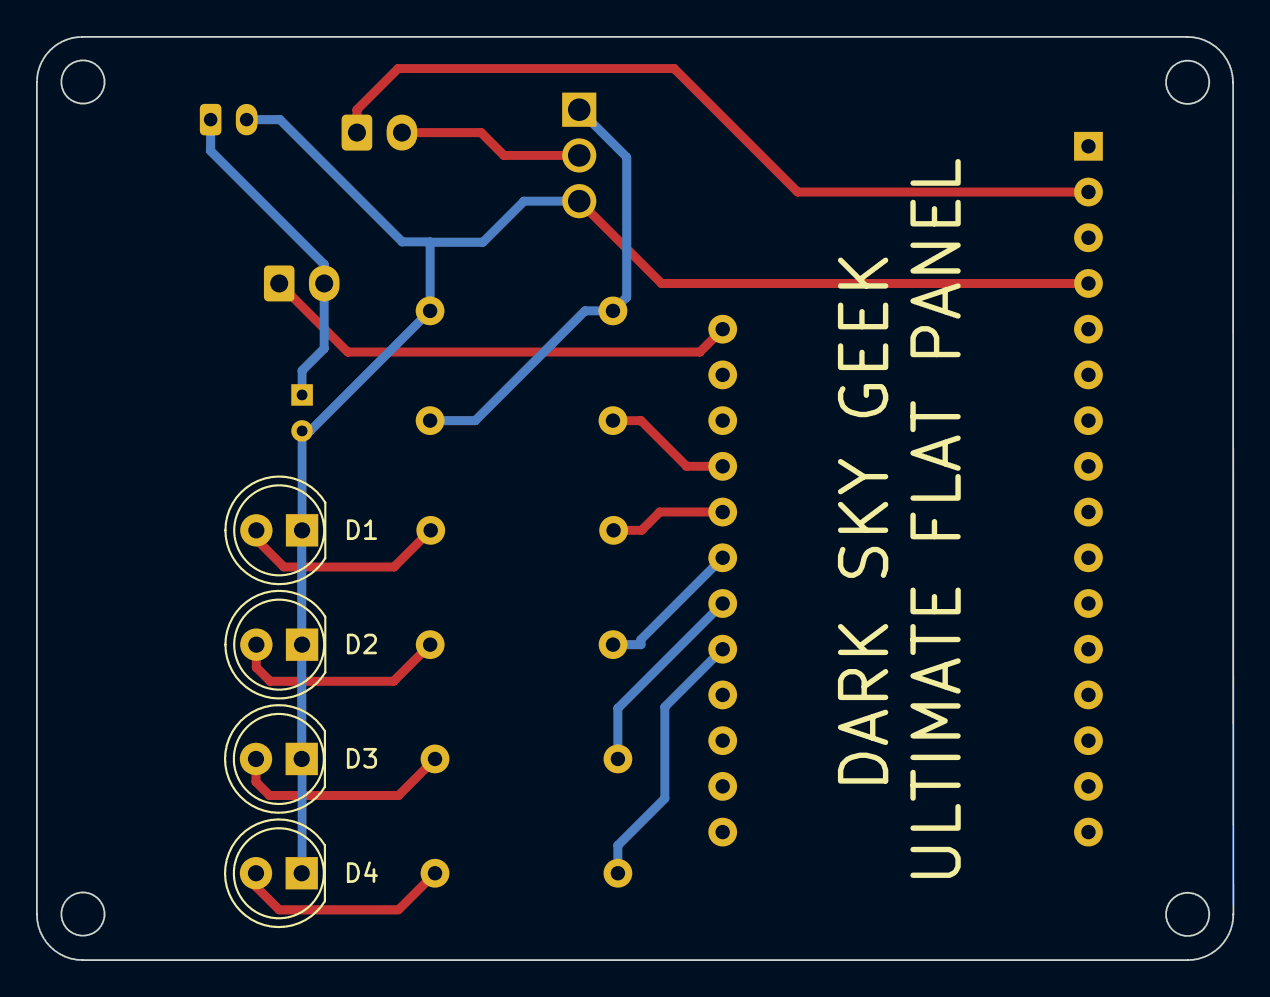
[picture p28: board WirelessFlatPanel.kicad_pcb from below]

Board: 2 copper layers, 66.5 x 51.3 mm, 16 parts (4 on the bottom side), 15 nets.

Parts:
10µF: 10µF; CP_Radial_D4.0mm_P2.00mm
- BAT +: JST-PH Bat; JST_PH_B2B-PH-K_1x02_P2.00mm_Vertical
- LED +: JST-XH LED; JST_XH_B2B-XH-A_1x02_P2.50mm_Vertical
A1: Adafruit Feather nRF52840 Express; Adafruit_Feather
D1, D2, D3, D4: LED; LED_D5.0mm
Q1: Val**; FQP30N06L
R1, R2, R3, R4, R5: 330Ω; R_Axial_DIN0207_L6.3mm_D2.5mm_P10.16mm_Horizontal
R6: 5KΩ; R_Axial_DIN0207_L6.3mm_D2.5mm_P10.16mm_Horizontal
Switch: JST-XH Switch; JST_XH_B2B-XH-A_1x02_P2.50mm_Vertical

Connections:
GND: 10µF.2, - BAT +.2, A1.4 (GND), D1.1 (K), D2.1 (K), D3.1 (K), D4.1 (K), Q1.3 (S), R6.1
unnamed: - LED +.1, A1.2 (3V3)
unnamed: A1.21 (D9), R4.2
unnamed: A1.22 (D10), R3.2
unnamed: A1.23 (D11), R2.2
unnamed: A1.24 (D12), R1.2
unnamed: A1.28 (VBAT), Switch.1
unnamed: 10µF.1, - BAT +.1, Switch.2
unnamed: D1.2 (A), R1.1
unnamed: D2.2 (A), R2.1
unnamed: D3.2 (A), R3.1
unnamed: D4.2 (A), R4.1
unnamed: Q1.1 (G), R5.1, R6.2
unnamed: - LED +.2, Q1.2 (D)
unnamed: A1.25 (D13), R5.2

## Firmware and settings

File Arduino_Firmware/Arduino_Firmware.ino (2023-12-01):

/*
 * Arduino_Firmware.ino
 * Copyright (C) 2023 - Present, Julien Lecomte - All Rights Reserved
 * Licensed under the MIT License. See the accompanying LICENSE file for terms.
 */

// This will fail to compile if you don't have an nRF52 board.
// In the future, we might have to open this up to other architectures.
#if !defined(ARDUINO_ARCH_NRF52) && !defined(ARDUINO_NRF52_ADAFRUIT)
#error "This firmware only supports boards with an NRF52 processor."
#endif

// The "standard" ArduinoBLE library seems to be incompatible with the Adafruit
// nRF52 Feather Express board. Thankfully, Adafruit maintains a library named
// Bluefruit, which we include here. The documentation is available at:
// https://learn.adafruit.com/bluefruit-nrf52-feather-learning-guide/bluefruit-nrf52-api
#include <bluefruit.h>

// Uncomment this to debug the firmware when the device is connected via USB.
// Do not forget to comment it out before flashing the final version, or the
// device will not work when it is not connected to a computer via USB...
// #define DEBUG

const BLEUuid SERVICE_UUID("0d389e0f-25dc-4070-9135-400b81e543ce");
const BLEUuid CHARACTERISTIC_UUID("2a0f87c9-7270-4c3e-aaa3-647961dfffa3");

// Bluetooth® Low Energy Calibrator Service
BLEService calibratorService(SERVICE_UUID);

// Bluetooth® Low Energy Flat Panel Switch Characteristic
BLECharacteristic calibratorCharacteristic(CHARACTERISTIC_UUID);

#define VBATPIN A6

// Voltage indicator LED pins
#define VBATLED1 9
#define VBATLED2 10
#define VBATLED3 11
#define VBATLED4 12

// Pin controlling the intensity of the flat pane
#define LED_CONTROL_PIN 13

const uint16_t MIN_BRIGHTNESS = 0;
const uint16_t MAX_BRIGHTNESS = 1023;

const uint32_t LED_TOKEN = 0x004c4544; // LED in ASCII :)

HardwarePWM *pwm = NULL;

// The mode we are in, which controls the behavior of the indicator LEDs.
// Defaults to BATTERY_INDICATOR when the device is turned on.
enum Mode {
  BATTERY_INDICATOR,
  DEVICE_CONNECTED,
  DEVICE_DISCONNECTED
} mode = BATTERY_INDICATOR;

// Variable used to blink the red LED to indicate that no device is currently connected.
bool deviceConnectedLED_ON = false;

void setup() {
#ifdef DEBUG
  Serial.begin(9600);
  while (!Serial) ;
#endif

  pinMode(VBATLED1, OUTPUT);
  pinMode(VBATLED2, OUTPUT);
  pinMode(VBATLED3, OUTPUT);
  pinMode(VBATLED4, OUTPUT);

  bool succeeded = configurePinPWM();

  if (!succeeded) {
    // Light up built-in LED to show that there was a problem...
    digitalWrite(LED_BUILTIN, HIGH);
    return;
  }

  // Initialize brightness (i.e., PWM duty cycle) to 0.
  setBrightness(MIN_BRIGHTNESS);

  Bluefruit.begin();

  Bluefruit.setName("DarkSkyGeek Calibrator");

  // Set the connect/disconnect callback handlers
  Bluefruit.Periph.setConnectCallback(connect_callback);
  Bluefruit.Periph.setDisconnectCallback(disconnect_callback);

  // Configure and start the calibrator service
  calibratorService.begin();

  // Configure our characteristic
  // Note: A BLECharacteristic is automatically be added to the last BLEService
  // that had it's `.begin()` function called.
  calibratorCharacteristic.setProperties(CHR_PROPS_READ | CHR_PROPS_WRITE);
  calibratorCharacteristic.setPermission(SECMODE_OPEN, SECMODE_OPEN);
  calibratorCharacteristic.setFixedLen(2);
  calibratorCharacteristic.setWriteCallback(write_callback);
  calibratorCharacteristic.begin();
  // Set the initial value for the characteristic:
  calibratorCharacteristic.write16(MIN_BRIGHTNESS);

  // Advertise device name in secondary scan response packet (optional)
  // (there is no room for 'Name' in advertising packet)
  Bluefruit.ScanResponse.addName();

  // Advertise BLE Calibrator Service
  Bluefruit.Advertising.addService(calibratorService);
  Bluefruit.Advertising.restartOnDisconnect(true);
  Bluefruit.Advertising.setInterval(32, 244); // in unit of 0.625 ms
  Bluefruit.Advertising.setFastTimeout(30); // number of seconds in fast mode
  Bluefruit.Advertising.start(0); // 0 = Don't stop advertising after n seconds

  if (Serial) {
    uint8_t addr[BLE_GAP_ADDR_LEN];
    Bluefruit.getAddr(addr);
    char sz_addr[40];
    format_ble_addr(addr, sz_addr);
    Serial.print("BLE device initialized. Bluetooth address is: ");
    Serial.println(sz_addr);
  }

  // Blink built-in LED a few times to show that initialization succeeded
  for (int i = 0; i < 5; i++) {
    digitalWrite(LED_BUILTIN, HIGH);
    delay(300);
    digitalWrite(LED_BUILTIN, LOW);
    delay(300);
  }
}

bool configurePinPWM() {
  bool succeeded = false;

  // Add pin to one of the available Hw PWM

  // First, use existing HWPWM modules (already owned by LED)
  for (int i = 0; i < HWPWM_MODULE_NUM; i++) {
    if (HwPWMx[i]->isOwner(LED_TOKEN) && HwPWMx[i]->addPin(LED_CONTROL_PIN)) {
      pwm = HwPWMx[i];
      succeeded = true;
      break;
    }
  }

  // If we could not add to existing owned PWM modules, try to add to a new PWM module.
  if (!succeeded) {
    for (int i = 0; i < HWPWM_MODULE_NUM; i++) {
      if (HwPWMx[i]->takeOwnership(LED_TOKEN) && HwPWMx[i]->addPin(LED_CONTROL_PIN)) {
        pwm = HwPWMx[i];
        succeeded = true;
        break;
      }
    }
  }

  if (succeeded) {
    pinMode(LED_CONTROL_PIN, OUTPUT);

    // Set PWM frequency:
    // - Base clock frequency = 8MHz (PWM_PRESCALER_PRESCALER_DIV_2)
    // - PWM counter max value = 1024
    // Frequency = 8MHz / 1024 = ~3.92kHz
    // We want the frequency to be high enough to not cause any flickering
    // when taking flats with a short exposure (particularly important with
    // a luminance filter where a 0.1 second exposure may be used due to the
    // sensitivity of modern day CMOS cameras) But we also don't want the
    // frequency to be too high either because the MOSFET capacitance and the
    // gate resistor will cause issues at low duty cycle values because the
    // gate voltage will not have enough time to rise to turn the MOSFET on,
    // so the LED strip will not turn on at all...

    // 1=16MHz, -> 2=8MHz <-, 4=4MHz, 8=2MHz, 16=1MHz, 32=500kHz, 64=250kHz, 128=125kHz
    pwm->setClockDiv(PWM_PRESCALER_PRESCALER_DIV_2);

    // Set the resolution to 10 bits since the max value is 1023 (2^10-1)
    // This calls pwm->setMaxValue(1023), thereby setting the PWM counter maximum value to 1023.
    pwm->setResolution(10);
  }

  return succeeded;
}

void connect_callback(uint16_t conn_handle)
{
  mode = DEVICE_CONNECTED;

  if (Serial) {
    BLEConnection* connection = Bluefruit.Connection(conn_handle);

    // Print central device name
    char central_name[32] = { 0 };
    connection->getPeerName(central_name, sizeof(central_name));
    Serial.print("Connected to central device: ");
    Serial.print(central_name);

    // Print central device address
    Serial.print(". Bluetooth address is: ");
    uint8_t* central_addr = connection->getPeerAddr().addr;
    char sz_addr[40];
    format_ble_addr(central_addr, sz_addr);
    Serial.println(sz_addr);
  }
}

void disconnect_callback(uint16_t conn_handle, uint8_t reason)
{
  mode = DEVICE_DISCONNECTED;

  // Reset the value for the characteristic. It does not invoke the write
  // callback, so we "manually" turn off the LED strip as well...
  calibratorCharacteristic.write16(MIN_BRIGHTNESS);
  setBrightness(MIN_BRIGHTNESS);

  if (Serial) {
    Serial.print("Disconnected, reason = 0x");
    Serial.println(reason, HEX);
    Serial.println("Advertising!");
  }
}

void write_callback(uint16_t conn_hdl, BLECharacteristic* chr, uint8_t* data, uint16_t len)
{
  if (Serial) {
    Serial.print("data[0] = ");
    Serial.println(data[0]);
    Serial.print("data[1] = ");
    Serial.println(data[1]);
  }

  uint16_t value = (data[0] << 8) + data[1];

  if (Serial) {
    Serial.print("Received value: ");
    Serial.println(value);
  }

  // Change brightness of LED strip accordingly...
  setBrightness(value);
}

void setBrightness(uint16_t value)
{
  pwm->writePin(LED_CONTROL_PIN, value);
}

void format_ble_addr(uint8_t* addr, char *s)
{
  for (int i = 0; i < BLE_GAP_ADDR_LEN; i++) {
    sprintf(&s[i*5], "0x%02X%s", addr[i], i < BLE_GAP_ADDR_LEN - 1 ? " " : "");
  }
}

void loop()
{
  switch (mode) {
    case BATTERY_INDICATOR:
      // We remain in the BATTERY_INDICATOR mode for only 5 seconds because:
      // 1) Those bright LEDs will be obnoxious at a dark site!
      // 2) We can use the red LED to indicate whether a device is connected, which can be useful.
      if (millis() < 5000) {
        // Code snippet from Adafruit website to measure the battery voltage
        float measuredvbat = analogRead(VBATPIN);
        measuredvbat *= 2;    // we divided by 2, so multiply back
        measuredvbat *= 3.6;  // Multiply by 3.6V, our reference voltage
        measuredvbat /= 1024; // convert to voltage

        // Update our battery voltage indicator LEDs:
        digitalWrite(VBATLED1, measuredvbat > 3.2 ? HIGH : LOW);
        digitalWrite(VBATLED2, measuredvbat > 3.4 ? HIGH : LOW);
        digitalWrite(VBATLED3, measuredvbat > 3.6 ? HIGH : LOW);
        digitalWrite(VBATLED4, measuredvbat > 3.8 ? HIGH : LOW);

        // (nit) This is to ensure the blinking starts as soon as the
        // state changes, without incurring an odd 0.5 second delay:
        deviceConnectedLED_ON = measuredvbat > 3.2;

        break;
      }

      mode = DEVICE_DISCONNECTED;

      digitalWrite(VBATLED2, LOW);
      digitalWrite(VBATLED3, LOW);
      digitalWrite(VBATLED4, LOW);

      // Intentional fallthrough...

    case DEVICE_DISCONNECTED:
      // Blink red LED:
      deviceConnectedLED_ON = !deviceConnectedLED_ON;
      digitalWrite(VBATLED1, deviceConnectedLED_ON ? HIGH : LOW);
      break;

    case DEVICE_CONNECTED:
      // Turn red LED on:
      digitalWrite(VBATLED1, HIGH);

      // (nit) This is to ensure the blinking starts as soon as the
      // state changes, without incurring an odd 0.5 second delay:
      deviceConnectedLED_ON = true;
      break;
  }

  delay(500);
}

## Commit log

2023-03-17 Lower PWM frequency to a more reasonable value
2023-03-19 Added ASCOM driver and license file
2023-03-19 Updated device name
2023-03-24 Added KiCad project
    [WirelessFlatPanel.kicad_pcb, WirelessFlatPanel.kicad_sch]
2023-03-27 Added images of PCB
2023-04-20 Simplification of the wireless flat panel
2023-04-20 Updated KiCad project to greatly simplify wiring
    [WirelessFlatPanel.kicad_pcb, WirelessFlatPanel.kicad_sch]
2023-04-21 Updated PCB footprint
    [WirelessFlatPanel.kicad_pcb]
2023-04-21 Updated FQP30N06 footprint
    [WirelessFlatPanel.kicad_pcb]
2023-11-05 Updated KiCad project
    [WirelessFlatPanel.kicad_pcb]
2023-11-05 Added FreeCAD model
    [FreeCAD_Model.FCStd]
2023-11-06 Updated 3D design and exported STL files for Askar 151PHQ
    [Body.stl, Circuit_Board_Box.stl, Cover.stl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]
2023-11-06 Updated 3D model
    [FreeCAD_Model.FCStd]
2023-11-11 Updated README and 3D model
    [FreeCAD_Model.FCStd]
2023-12-01 Updated behavior of indicator LEDs
2024-01-13 Added capacitors to BOM
2024-01-13 Updated BOM
2024-01-14 Added PCBWay instructions
2024-01-14 Added note about Taloya's LED ceiling light availability
2024-01-17 Fixed a couple of issues reported
    [FreeCAD_Model.FCStd]

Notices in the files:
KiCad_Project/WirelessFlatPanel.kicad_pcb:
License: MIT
